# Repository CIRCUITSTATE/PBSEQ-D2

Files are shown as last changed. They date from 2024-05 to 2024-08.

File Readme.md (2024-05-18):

# PBSEQ-D2

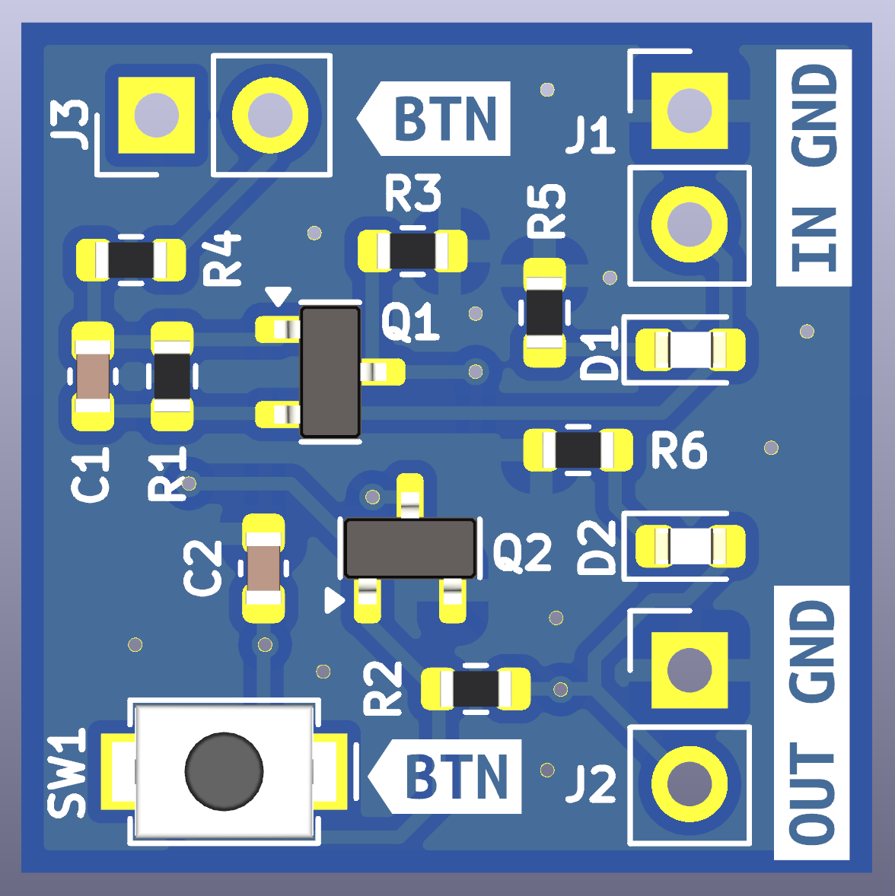
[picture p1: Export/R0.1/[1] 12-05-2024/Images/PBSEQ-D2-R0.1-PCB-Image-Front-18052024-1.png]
PBSEQ-D2 Front


**PBSEQ-D2** is a simple push-button based power sequencer demo board designed in KiCad. You can press the push-button momentarily to turn on the output. Pressing again will turn off the output. A PMOS transistor is used as a high-side switch to control the power. An NMOS transistor controls the power sequencing. This demo project is fully open-source and you can find the source design files here.

A tutorial of designing and testing the circuit will soon be available at [CIRCUITSTATE](https://www.circuitstate.com/).

## Project Details

- **Parent Project:** PBSEQ
- **Variant Name:** PBSEQ-D2
- **Latest Revision:** `R0.1`
- **EDA Tools:** KiCad V8
- **Layer Count:** 2
- **Board Thickness:** 1.6 mm
- **Dimensions:** 19 x 19 mm

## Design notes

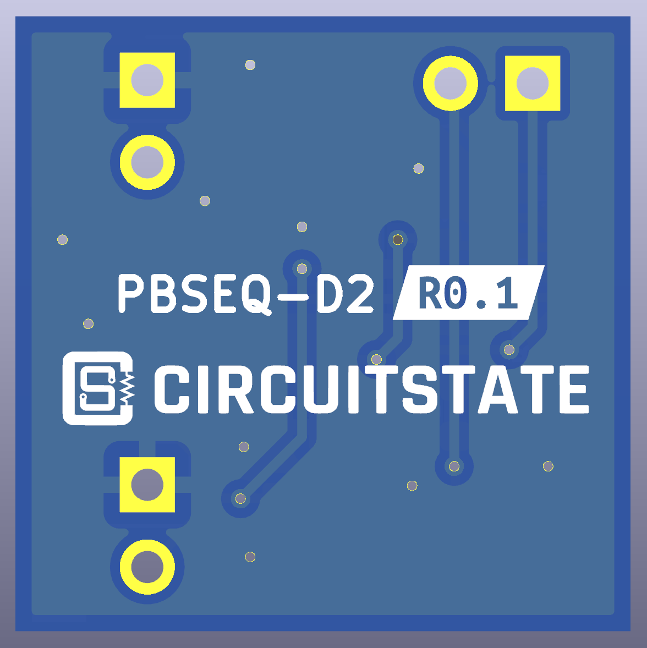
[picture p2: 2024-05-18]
Export/R0.1/[1] 12-05-2024/Images/PBSEQ-D2-R0.1-PCB-Image-Back-18052024-1.png

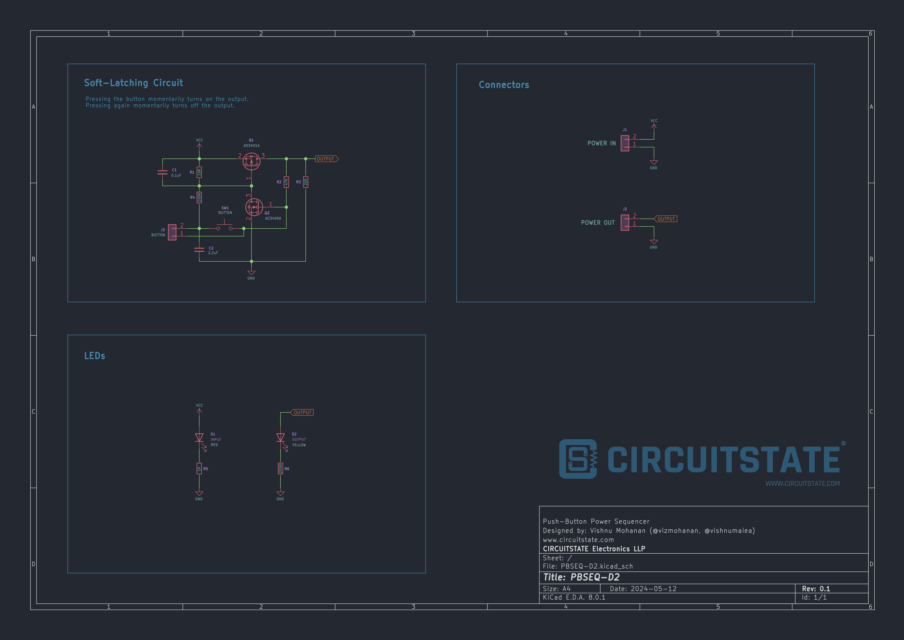
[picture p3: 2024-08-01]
Export/R0.1/[1] 12-05-2024/SCH/PBSEQ-D2-R0.1-SCH-12052024-1_1.png

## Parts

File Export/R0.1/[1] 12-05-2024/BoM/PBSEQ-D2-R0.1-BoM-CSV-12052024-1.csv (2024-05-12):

# | Reference | Value | Name | Footprint | Qty | MPN | MFR | DNP
1 | C1 | 0.1uF |  | Capacitor_SMD:C_0603_1608Metric | 1 | 0603B104J500CT | Walsin
2 | C2 | 2.2uF |  | Capacitor_SMD:C_0603_1608Metric | 1 | CL10A225KA8NNNC | Samsung
3 | D1 | RED | INPUT | LED_SMD:LED_0603_1608Metric | 1 | 19-21SURC/S530-A2/TR8 | Everlight
4 | D2 | YELLOW | OUTPUT | LED_SMD:LED_0603_1608Metric | 1 | 19-213/Y2C-FN2P2VZ/3T | Everlight
5 | J1 | POWER IN | POWER IN | Connector_PinHeader_2.54mm:PinHeader_1x02_P2.54mm_Vertical | 1 | DNP
6 | J2 | POWER OUT | POWER OUT | Connector_PinHeader_2.54mm:PinHeader_1x02_P2.54mm_Vertical | 1 | DNP
7 | J3 | BUTTON | BUTTON | Connector_PinHeader_2.54mm:PinHeader_1x02_P2.54mm_Vertical | 1 | DNP
8 | Q1 | AO3401A |  | Package_TO_SOT_SMD:SOT-23 | 1 | AO3401A | Alpha & Omega
9 | Q2 | AO3400A |  | Package_TO_SOT_SMD:SOT-23 | 1 | AO3400A | Alpha & Omega
10 | R1 | 10K |  | Resistor_SMD:R_0603_1608Metric | 1 | WR06X1002FTL | Walsin
11 | R2 | 47K |  | Resistor_SMD:R_0603_1608Metric | 1 | WR06X4702FTL | Walsin
12 | R3 | 22K |  | Resistor_SMD:R_0603_1608Metric | 1 | WR06X2202FTL | Walsin
13 | R4 | 100K |  | Resistor_SMD:R_0603_1608Metric | 1 | WR06X1003FTL | Walsin
14 | R5 | 1K |  | Resistor_SMD:R_0603_1608Metric | 1 | WR06X1001FTL | Walsin
15 | R6 | 200R |  | Resistor_SMD:R_0603_1608Metric | 1 | WR06X2000FTL | Walsin
16 | SW1 | BUTTON | BUTTON | CIRCUITSTATE_Switch_SMD:CK_SW_SPST_UK-B0273-SP25Y | 1 | TS-1088R-02526 | XUNPU

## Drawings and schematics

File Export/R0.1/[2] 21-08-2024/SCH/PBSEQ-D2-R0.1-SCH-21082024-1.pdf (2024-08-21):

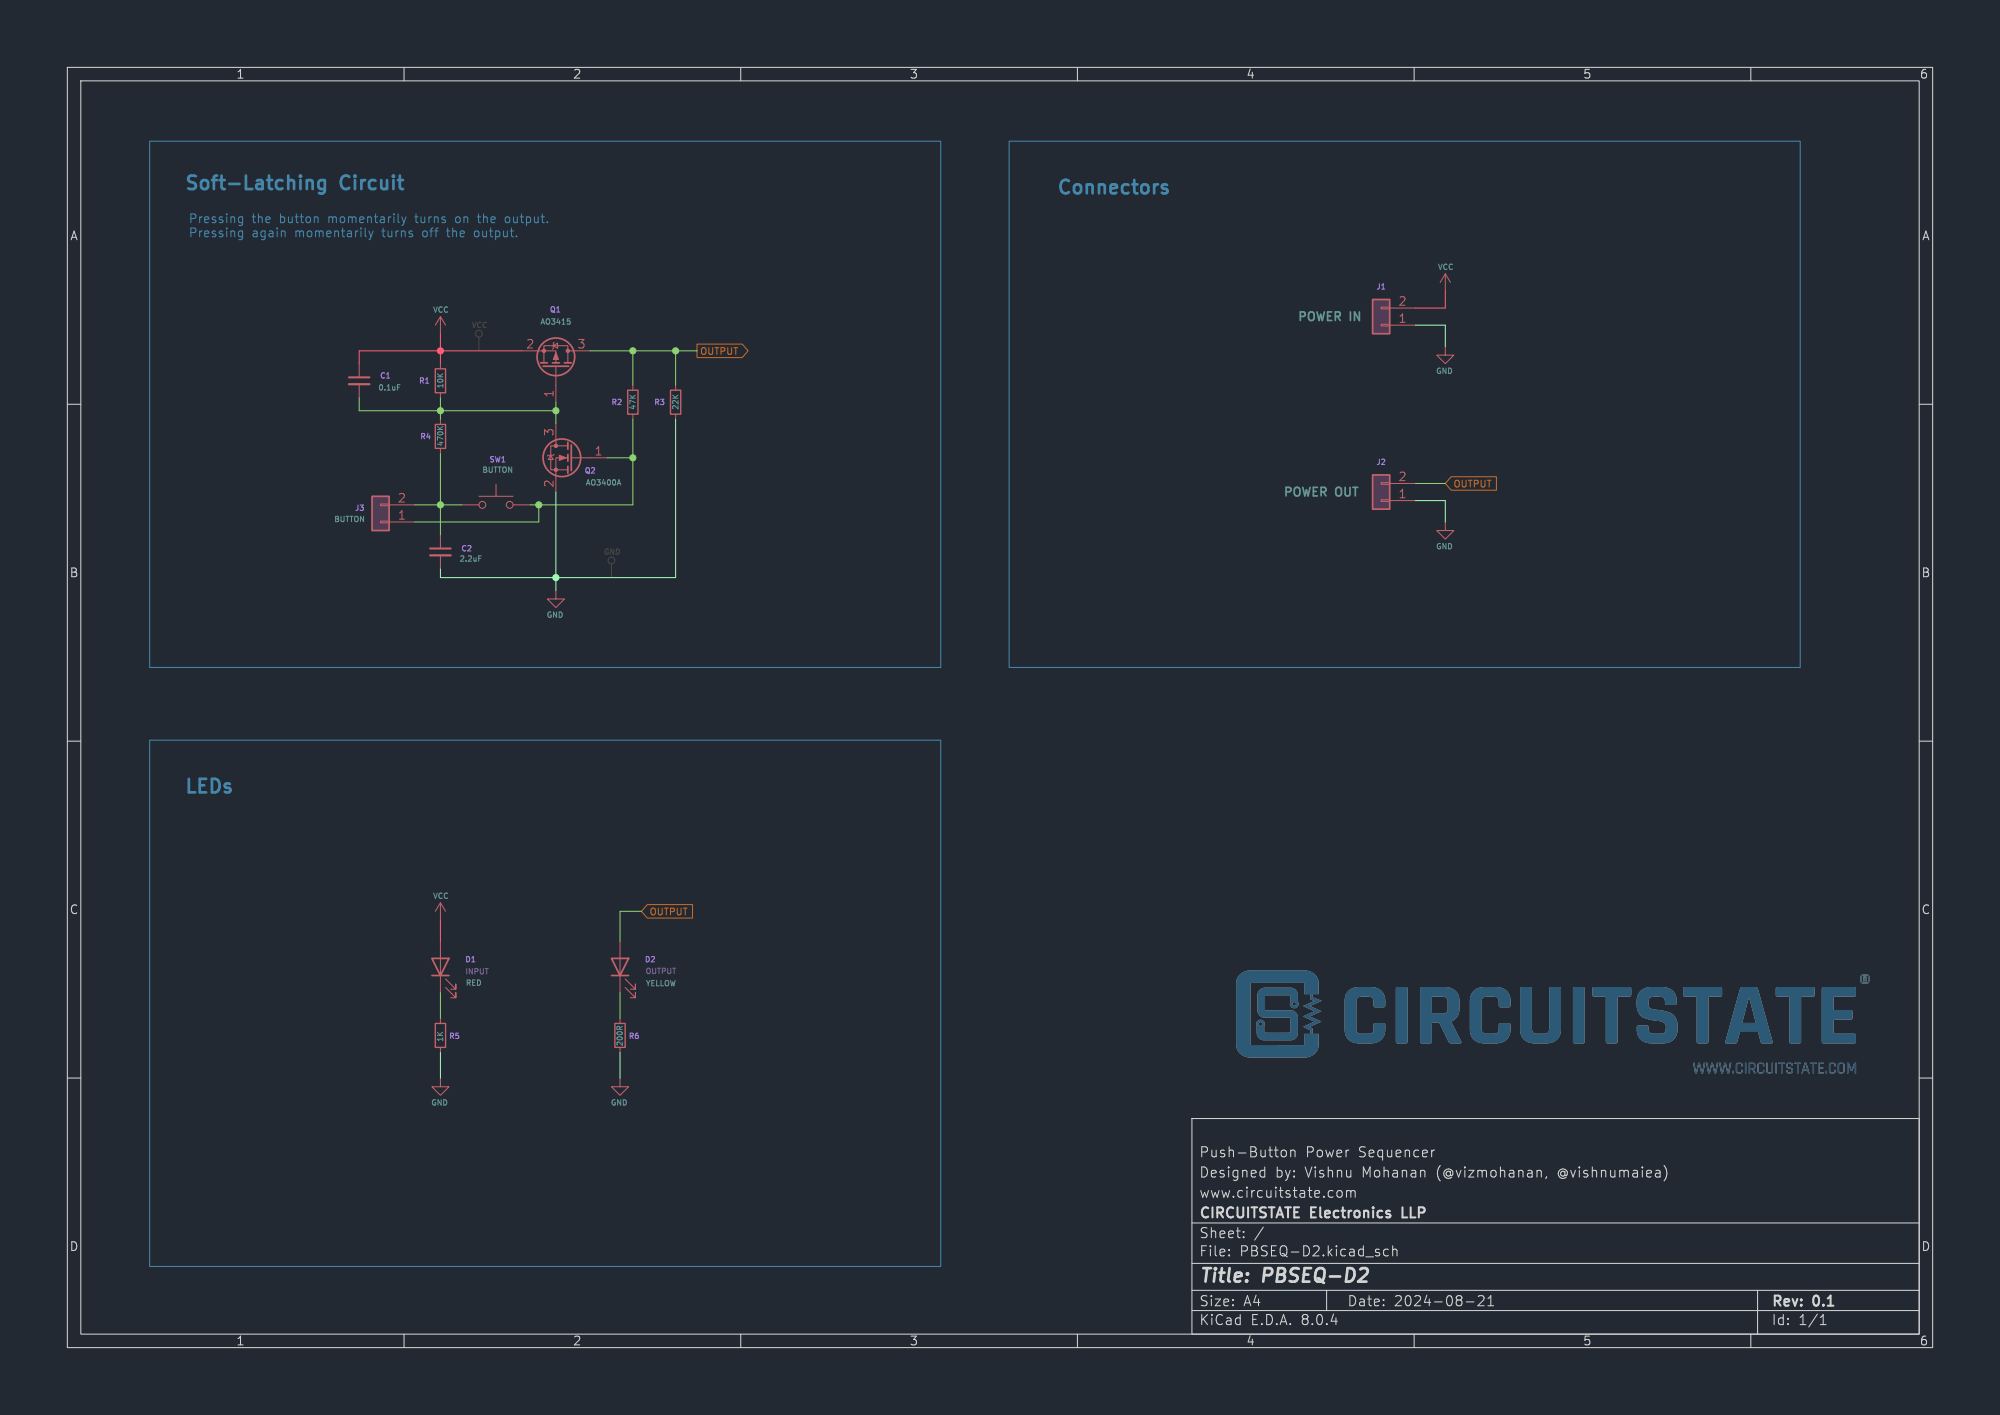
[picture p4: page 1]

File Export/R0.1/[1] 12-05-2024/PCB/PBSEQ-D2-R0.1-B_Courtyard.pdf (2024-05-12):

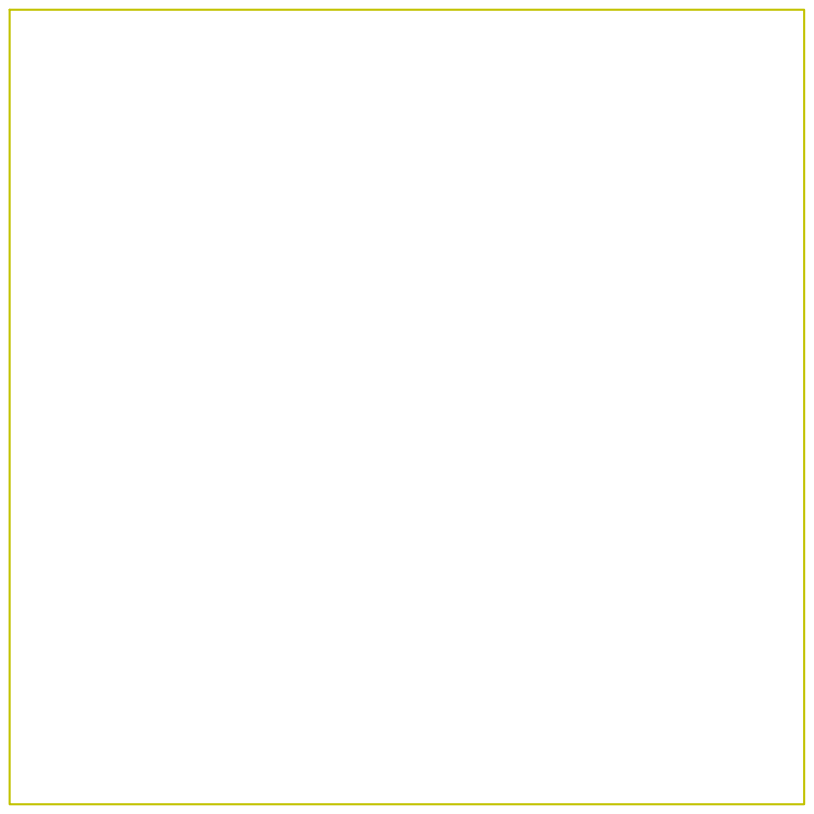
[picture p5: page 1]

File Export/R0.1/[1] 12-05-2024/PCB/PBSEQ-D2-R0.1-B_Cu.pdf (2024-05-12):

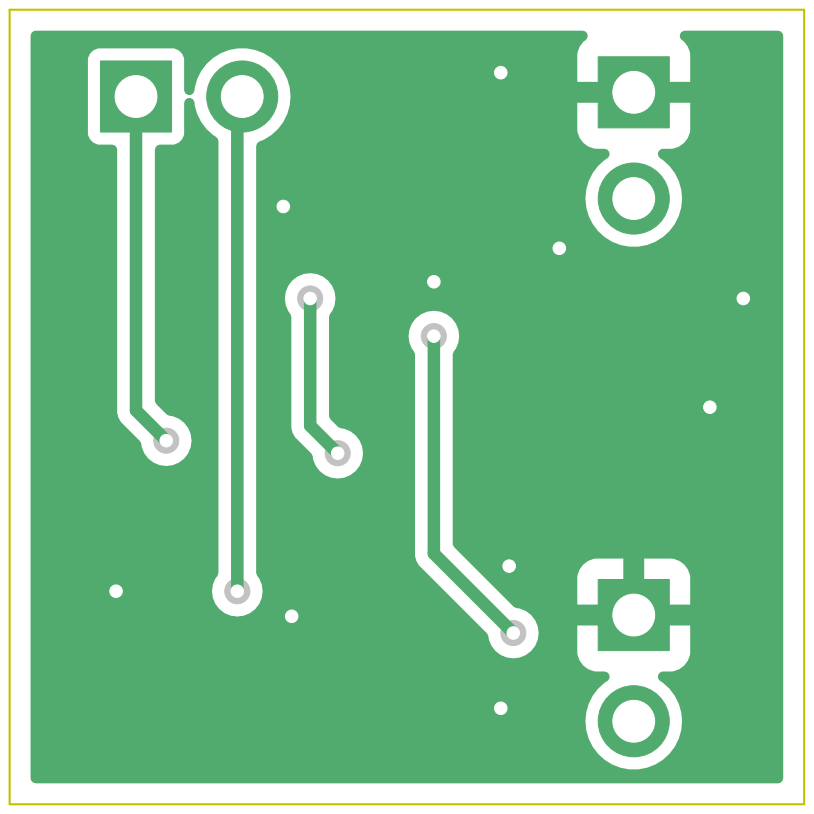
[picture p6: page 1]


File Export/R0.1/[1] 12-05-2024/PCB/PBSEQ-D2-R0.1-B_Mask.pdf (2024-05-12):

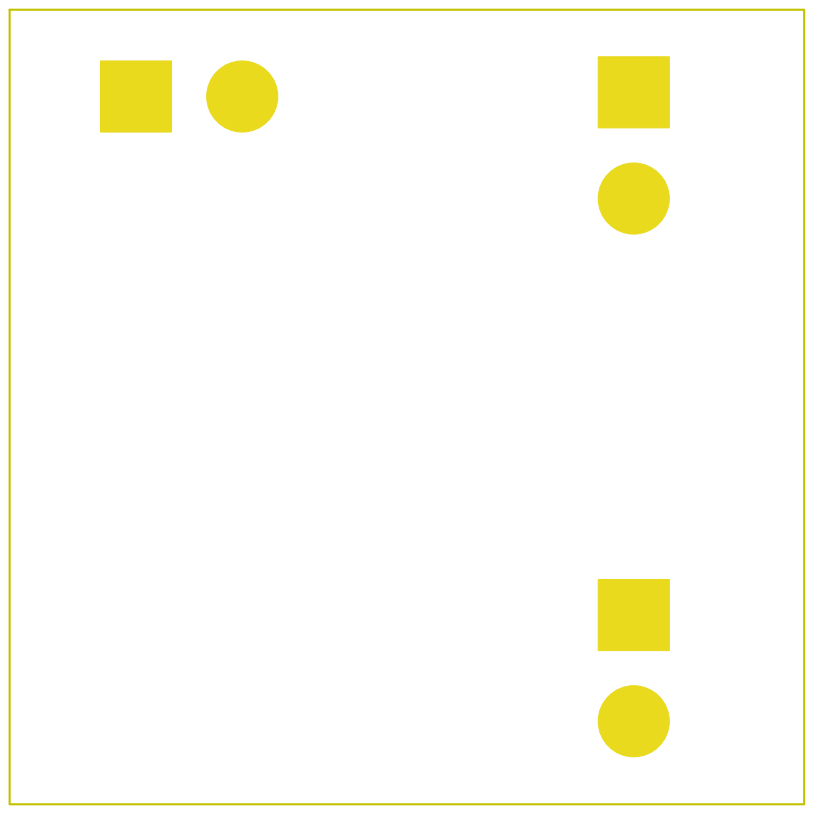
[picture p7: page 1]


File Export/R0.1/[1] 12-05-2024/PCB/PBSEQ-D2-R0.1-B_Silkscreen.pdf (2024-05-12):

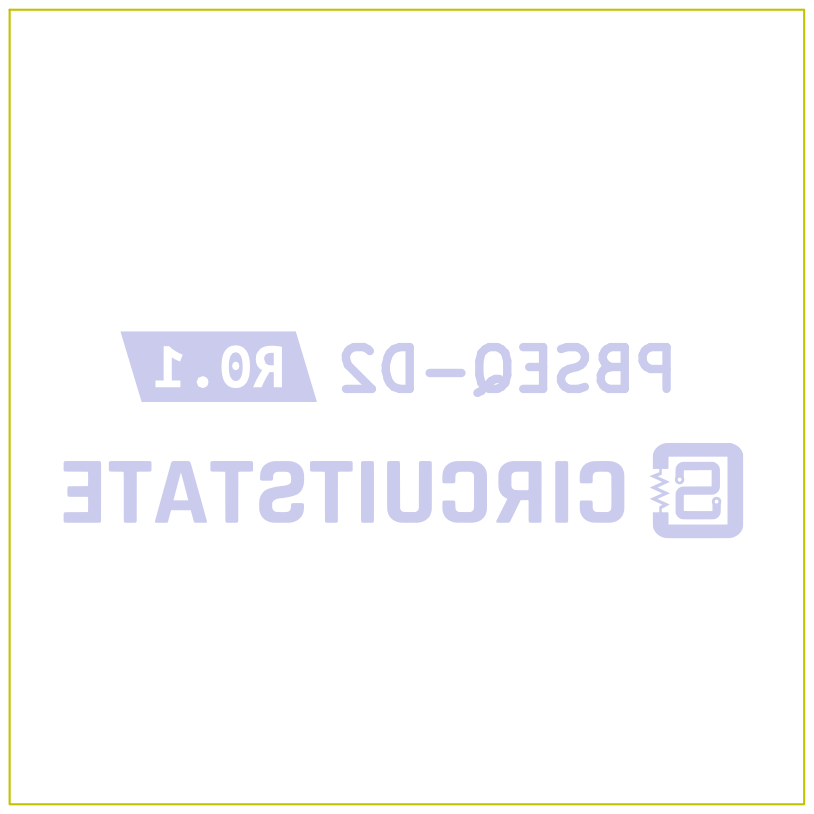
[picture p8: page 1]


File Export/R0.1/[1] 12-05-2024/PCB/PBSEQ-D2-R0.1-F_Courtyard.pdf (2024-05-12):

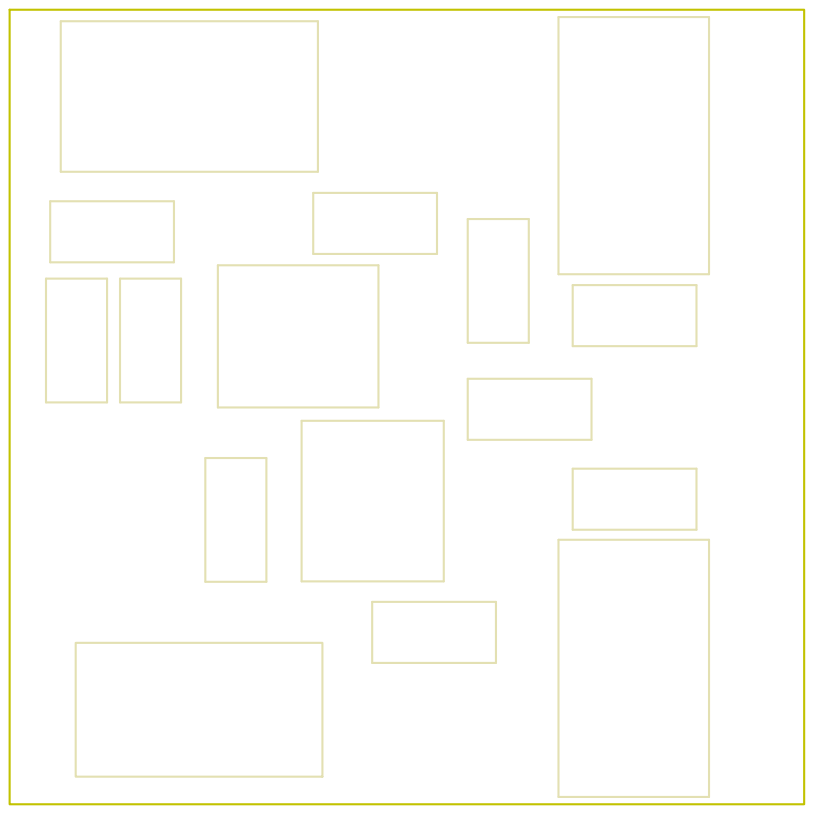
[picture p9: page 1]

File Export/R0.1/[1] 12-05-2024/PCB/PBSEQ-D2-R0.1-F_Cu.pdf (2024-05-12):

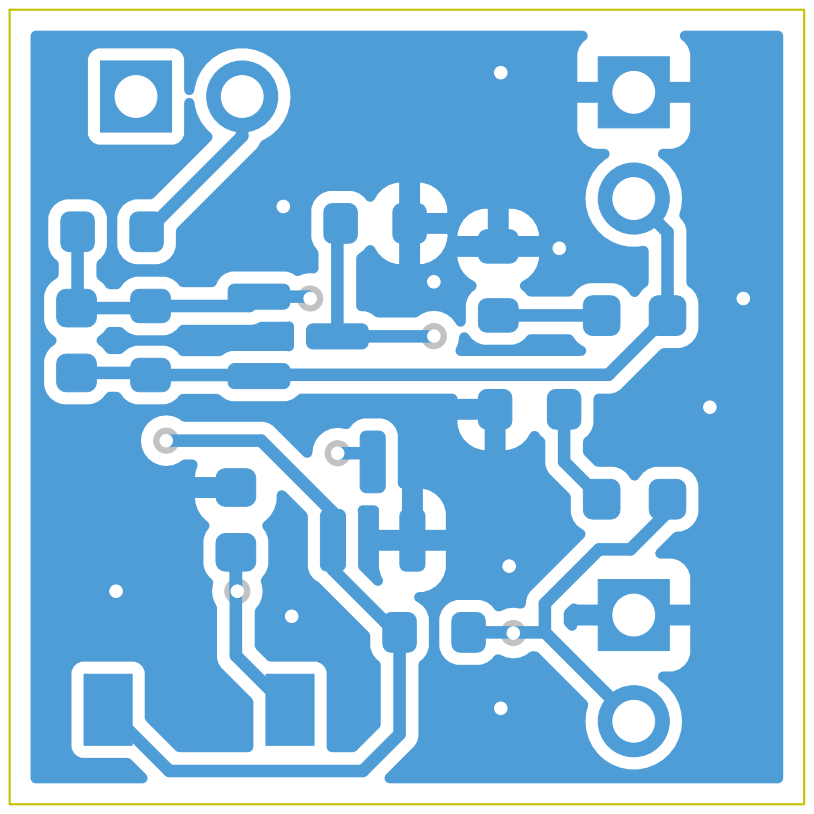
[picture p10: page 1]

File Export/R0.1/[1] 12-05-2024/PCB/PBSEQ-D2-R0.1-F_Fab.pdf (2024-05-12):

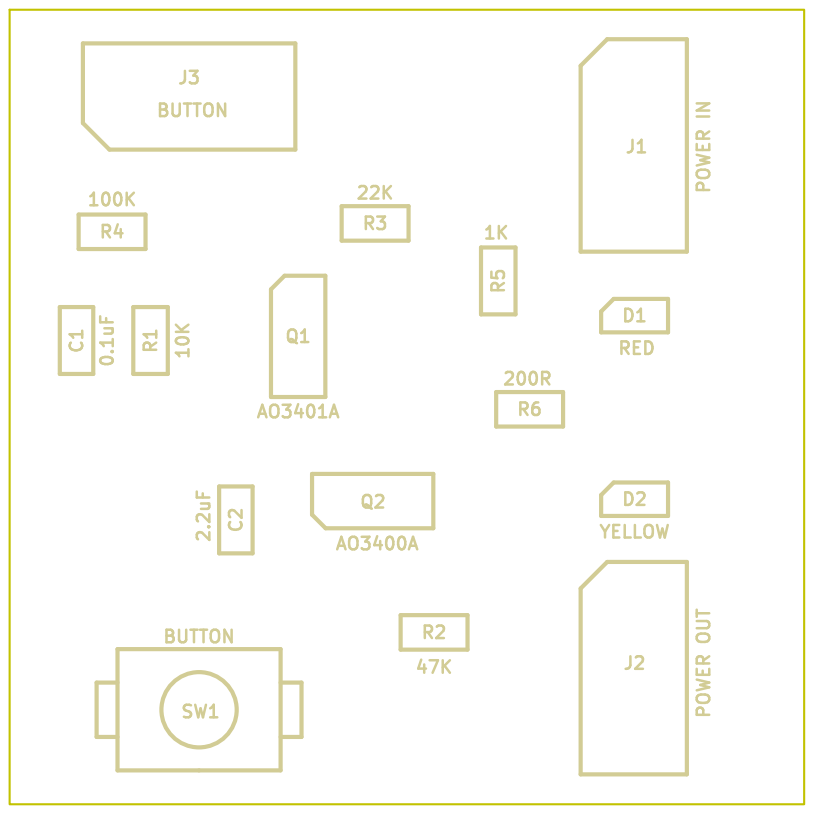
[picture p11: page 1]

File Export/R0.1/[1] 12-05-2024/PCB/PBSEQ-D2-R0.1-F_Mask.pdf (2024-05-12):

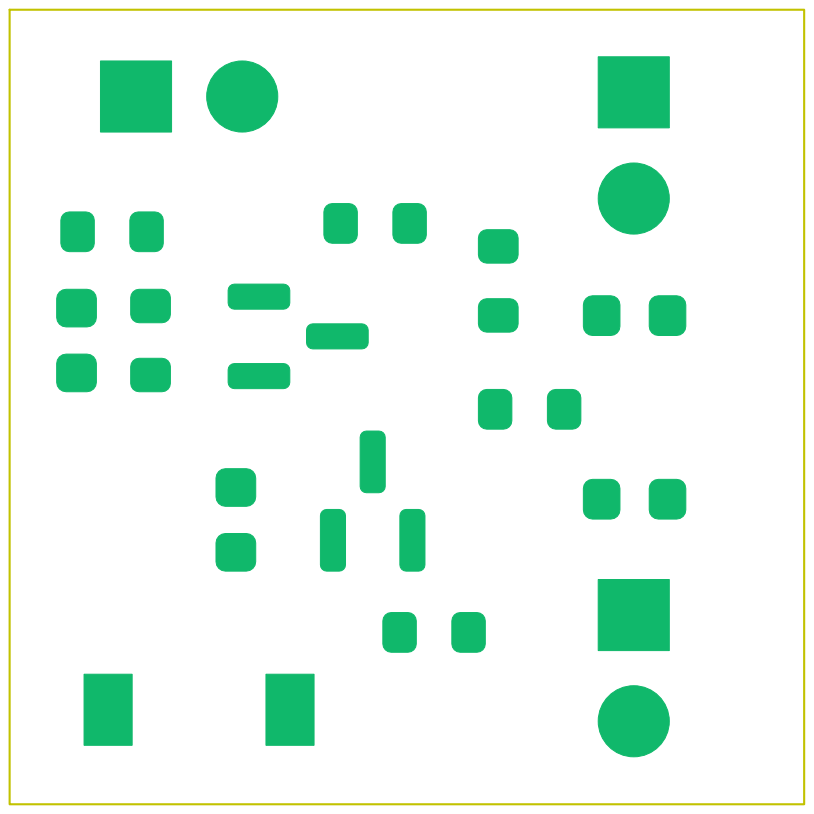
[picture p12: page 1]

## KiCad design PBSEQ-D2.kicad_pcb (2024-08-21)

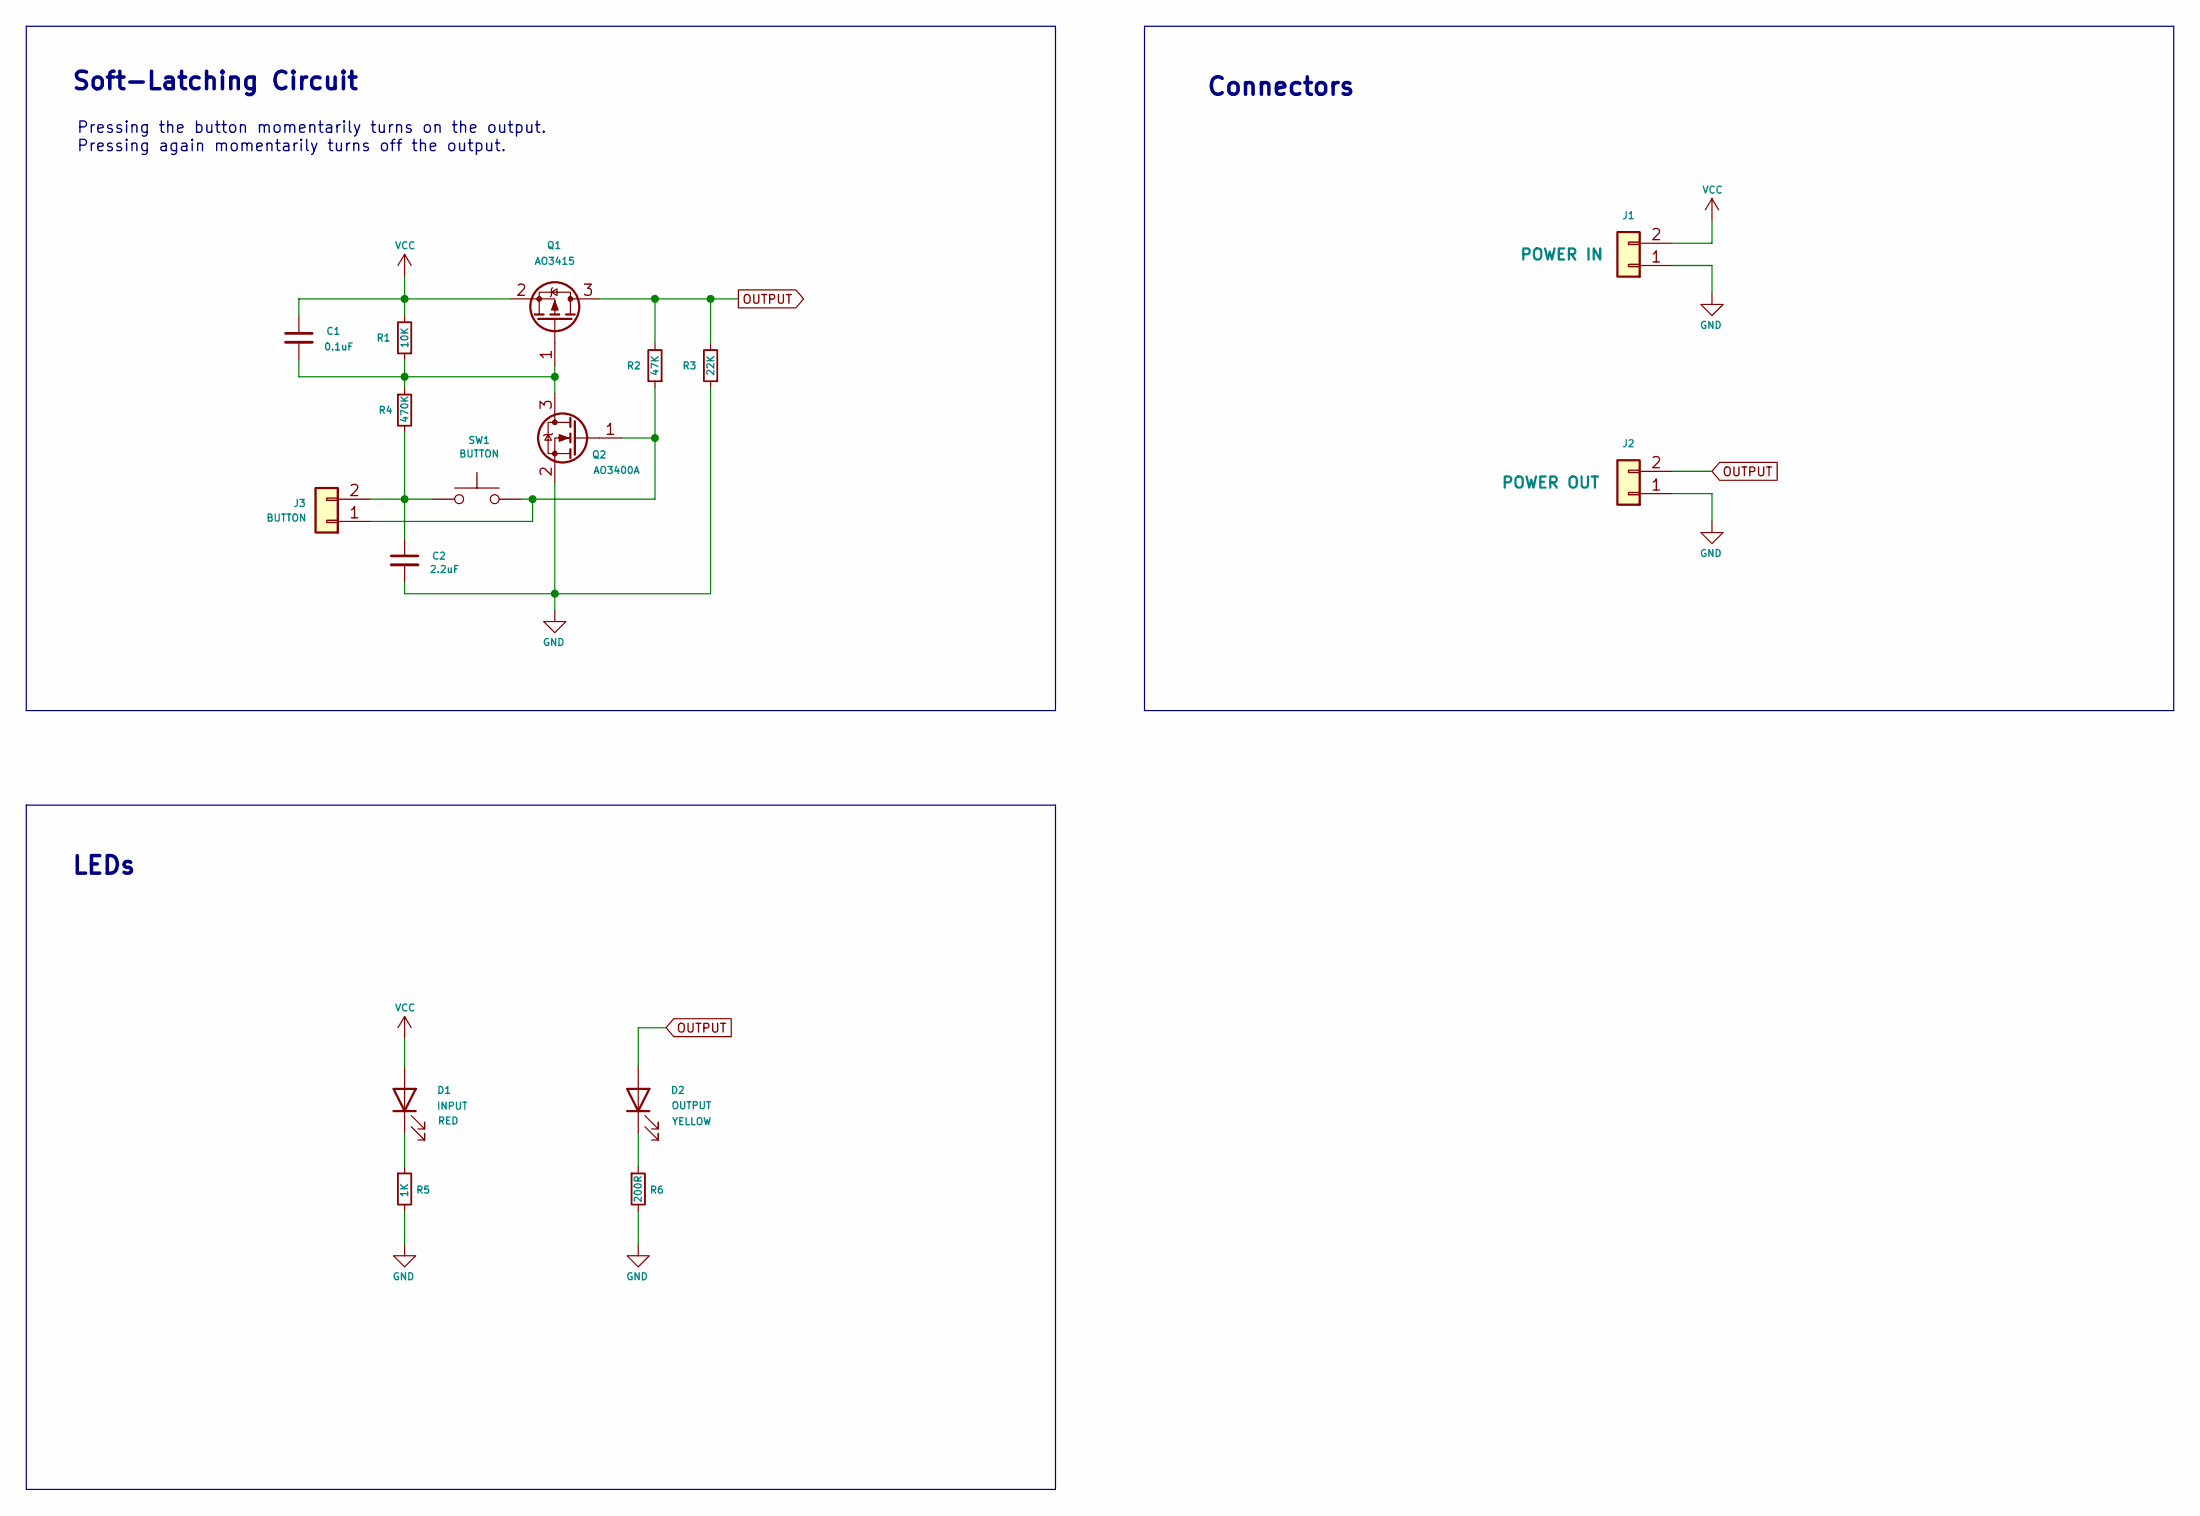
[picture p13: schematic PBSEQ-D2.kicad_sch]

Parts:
C1: 0.1uF; C_0603_1608Metric; MPN 0603B104J500CT
C2: 2.2uF; C_0603_1608Metric; MPN CL10A225KA8NNNC
D1: RED; LED_0603_1608Metric; MPN 19-21SURC/S530-A2/TR8
D2: YELLOW; LED_0603_1608Metric; MPN 19-213/Y2C-FN2P2VZ/3T
J1: POWER IN; PinHeader_1x02_P2.54mm_Vertical; MPN DNP
J2: POWER OUT; PinHeader_1x02_P2.54mm_Vertical; MPN DNP
J3: BUTTON; PinHeader_1x02_P2.54mm_Vertical; MPN DNP
Q1: AO3415; SOT-23; MPN AO3415
Q2: AO3400A; SOT-23; MPN AO3400A
R1: 10K; R_0603_1608Metric; MPN WR06X1002FTL
R2: 47K; R_0603_1608Metric; MPN WR06X4702FTL
R3: 22K; R_0603_1608Metric; MPN WR06X2202FTL
R4: 470K; R_0603_1608Metric; MPN WR06X4703FTL
R5: 1K; R_0603_1608Metric; MPN WR06X1001FTL
R6: 200R; R_0603_1608Metric; MPN WR06X2000FTL
SW1: BUTTON; CK_SW_SPST_UK-B0273-SP25Y; MPN TS-1088R-02526

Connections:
GND: C2.2, J1.1, J2.1, Q2.2 (S), R3.1, R5.2, R6.2
unnamed: D1.1 (K), R5.1
unnamed: D2.1 (K), R6.1
unnamed: J3.1, Q2.1 (G), R2.1, SW1.2
unnamed: C2.1, J3.2, R4.2, SW1.1
unnamed: C1.2, Q1.1 (G), Q2.3 (D), R1.1, R4.1
OUTPUT: D2.2 (A), J2.2, Q1.3 (D), R2.2, R3.2
VCC: C1.1, D1.2 (A), J1.2, Q1.2 (S), R1.2

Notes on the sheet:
Soft-Latching Circuit
LEDs
Connectors
Pressing the button momentarily turns on the output. Pressing again momentarily turns off the output.

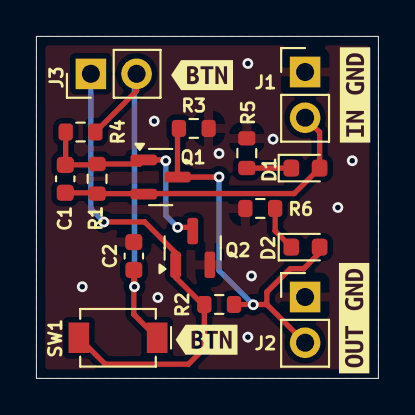
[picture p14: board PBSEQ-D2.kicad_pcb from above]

Board: 2 copper layers, 19.0 x 19.0 mm, 21 parts (1 on the bottom side), 8 nets.

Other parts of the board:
kibuzzard-663FBC0C, kibuzzard-663FBC0C#2: G***; kibuzzard-663FBC0C
kibuzzard-663FBCF2: G***; kibuzzard-663FBCF2
kibuzzard-663FBD0F: G***; kibuzzard-663FBD0F
kibuzzard-66404F66: G***; kibuzzard-66404F66

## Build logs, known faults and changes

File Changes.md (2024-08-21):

#
### **+05:30 10:37:45 PM 21-08-2024, Wednesday**

  * Added net highlights on the PCB.
  * Exported schematic file. There are no other changes to the schematic or PCB.

#
### **+05:30 08:37:25 PM 01-08-2024, Thursday**

  * Updated values of `R1` and `R4`. The new values are found to be working with practical testing.
  * Updated `Q1` value to `AO3415` based on testing.
  * Added net classes and highlights.
  * Updated BoM.
  * Imported new changes to the PCB.
  * No changes in the electrical design.

#
### **+05:30 11:39:08 AM 18-05-2024, Saturday**

  * Exported images.
  * Updated Readme. Added images.

#
### **+05:30 09:35:53 PM 12-05-2024, Sunday**

  * Updated Drill/Place origin.

#
### **+05:30 09:21:14 PM 12-05-2024, Sunday**

  * Routing completed.
  * DRC passes.
  * Generated manufacturing files.
  * Added Changes and Readme.
  * New Revision `R0.1`.

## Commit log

2024-05-12 R0.1 Init Commit
    * Routing completed.
    * DRC passes.
    * Generated manufacturing files.
    * Added Changes and Readme.
    * New Revision `R0.1`.
    [PBSEQ-D2-R0.1-BoM-CSV-12052024-1.csv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]
2024-05-12 Updated Drill/Place origin
    [PBSEQ-D2.kicad_pcb]
2024-08-01 Updated resistor values
    * Updated values of `R1` and `R4`. The new values are found to be working with practical testing.
    * Updated `Q1` value to `AO3415` based on testing.
    * Added net classes and highlights.
    * Updated BoM.
    * Imported new changes to the PCB.
    * No changes in the electrical design.
    [PBSEQ-D2.kicad_pcb, PBSEQ-D2.kicad_sch]
2024-08-21 Exported schematic
    * Added net highlights on the PCB.
    * Exported schematic file. There are no other changes to the schematic or PCB.
    [PBSEQ-D2.kicad_pcb, PBSEQ-D2.kicad_sch]
